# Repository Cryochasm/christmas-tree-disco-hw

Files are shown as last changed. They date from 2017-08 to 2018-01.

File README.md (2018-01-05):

# christmas-tree-disco-hw
KiCAD project for a Christmas Tree decoration.

Uses Texas Instruments LaunchPad **EK-TM4C123GXL** to control a 
shift register and RGB LEDs. Compatable with the 
430BOOST-C55AUDIO1 booster pack for the possibilty of timing 
the lights to music.

## Dependancies
* KiCAD nightly build
* KiBOM

## Folder Structure:  
- ***/PCB/***  
   Main Project: Christmas_Tree_Disco.pro  
   Top Level Schematic: Christmas_Tree_Disco.sch  
   Schematic Library: local.lib  

- ***/PCB/Fabrication***  
   PDFs of the schematics and PCB component layout  

- ***/PCB/Gerbers***  
   Generated gerber files  

- ***/PCB/local.pretty***  
   KiCad footprints used in this project  

- ***/PCB/local.pretty/packages3d***  
   3D models for the footprints

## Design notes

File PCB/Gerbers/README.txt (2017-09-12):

All files are in inches 
    
Format is 4.6mm

Solder-mask is Green 

Silkscreen is White

Surface finish is HASL
    
Copper weight is 1oz
    
PCB material is FR-4

PCB thickness is 1.6 mm

Layer Stackup is specified in the Fab Assembly file.

This section describes the function and purpose of the files.

    Christmas_Tree_Disco-B.Cu.gbr             Bottom copper layer
    Christmas_Tree_Disco-B.Fab.gbr            Bottom assembly layer
    Christmas_Tree_Disco-B.Mask.gbr           Bottom solder-mask layer
    Christmas_Tree_Disco-B.Paste.gbr          Bottom solder paste layer
    Christmas_Tree_Disco-B.SilkS.gbr          Bottom silkscreen layer
    Christmas_Tree_Disco-Edge.Cuts.gbr        Board outline
    Christmas_Tree_Disco-F.Cu.gbr             Top copper layer
    Christmas_Tree_Disco-F.Fab.gbr            Top assembly layer
    Christmas_Tree_Disco-F.Mask.gbr           Top solder-mask layer
    Christmas_Tree_Disco-F.Paste.gbr          Front solder paste layer
    Christmas_Tree_Disco-F.SilkS.gbr          Top silkscreen layer
    Christmas_Tree_Disco-PTH.drl              Plated through hole drill file
    Christmas_Tree_Disco.d356                 IPC-D-356 Netlist File
    Christmas_Tree_Disco-all-pos.csv          Pick and Place locations file

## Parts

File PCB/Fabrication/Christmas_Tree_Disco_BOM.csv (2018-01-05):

Have | Needed | Reference | Quantity | Value | Footprint | Datasheet | MPN | Description | Included in BOM
 | 35 | C0 C1 C10 C11 C12 C13 C14 C15 C2 C3 C4 C5 C6 C7 C9 | 15 | 0.1u | local:SMD-0805 | http://www.samsungsem.com/kr/support/library/product-catalog/mlcc.jsp | CL21B104KACWPNC | 0.1µF ±10% 25V Ceramic Capacitor X7R 0805 (2012 Metric) | Yes
1 | 3 | C16 C17 C8 | 3 | 10u | local:SMD-POL-1206 | http://datasheets.avx.com/F93.pdf | F931A106KAA | CAP TANT 10UF 10V 10% 1206 | Yes
12 | 25 | D0 D1 D10 D11 D12 D13 D14 D15 D2 D3 D4 D5 D6 D7 D9 | 15 | RGB LED | local:T-1_5mm | https://media.digikey.com/pdf/Data%20Sheets/Kingbright%20PDFs/WP154A4SEJ3VBDZGW-CA_Ver.1A_Jul-24-13.pdf | WP154A4SEJ3VBDZGW/CA | Red, Green, Blue (RGB) 625nm Red, 525nm Green, 470nm Blue LED Indication - Discrete 2.2V Red, 3.3V Green, 3.3V Blue Radial | Yes
 | N/A | D8 | 1 | SMBJ22D-M3/H | local:DO-214AA | http://www.vishay.com/docs/87606/87606.pdf | SMBJ22D-M3/H | TVS DIODE 22VWM 35.1VC DO214AA | Yes
 | N/A | F1 | 1 | 24V 3A | local:SMD-2920 | http://www.bourns.com/docs/Product-Datasheets/mflsmf.pdf | MF-LSMF300/24X-2 | Polymeric PTC Resettable Fuse 24V Ih Surface Mount 2920 (7351 Metric), Concave | Yes
 | 5 | H2 H4 | 2 | 2x10 HEADER | local:2x10_header_3d | http://www.molex.com/pdm_docs/sd/015912200_sd.pdf | 15912200 | 20 Positions Header, Breakaway Connector 0.100" (2.54mm) Surface Mount Tin | Yes
 | N/A | J1 | 1 | PJ-006B-SMT-TR | local:PJ-006B-SMT | http://www.cui.com/product/resource/pj-006b-smt.pdf | PJ-006B-SMT-TR | Power Barrel Connector Jack 2.50mm ID (0.098"), 5.50mm OD (0.217") Surface Mount | Yes
 | 3 | U2 | 1 | TLC5955DCA | local:HTSSOP-56_14x6.1 | http://www.ti.com/lit/ds/symlink/tlc5955.pdf | TLC5955DCAR | LED Driver IC 48 Output Linear Analog Dimming 30mA 56-HTSSOP | Yes
 | N/A | U3 | 1 | LM1085-5.0 | local:TO-263 | http://www.ti.com/lit/ds/symlink/lm1085.pdf | LM1085ISX-5.0/NOPB | Linear Voltage Regulator IC Positive Fixed Output 5V 3A DDPAK/TO-263-3 | Yes
 | N/A | H1 | 1 | LPRocket | local:LPRocket | - | - | - | No
 | N/A | H3 | 1 | Snow Silk Screen | local:snow | - | - | - | No
 | N/A | H5 | 1 | Power Supply 12V 24W | local:Do_Not_Populate | http://www.cui.com/product/resource/digikeypdf/swi24-n.pdf | SWI24-12-N-P6 | 12V 24W AC/DC External Wall Mount Adapter Fixed Blade Input | No
 | N/A | H6 | 1 | Power Info | local:Polarity | - | - | - | No
 | N/A | H7 | 1 | SPFMDBC | local:Open_Source_HW_Logo | - | - | - | No
 | 2 | U1 | 1 | DEV_KIT_EK-TM4C123GXL | local:DEV_KIT_EK-TM4C123GXL | http://www.ti.com/lit/ds/spms376e/spms376e.pdf | EK-TM4C123GXL | Development Boards & Kits - ARM TIVA LaunchPAD | No
 | 2 |  |  |  |  |  | 430BOOST-C55AUDIO1
 | N/A | V1.0 | 1 | www.github.com/Cryochasm | local:Cryochasm | - | - | - | No

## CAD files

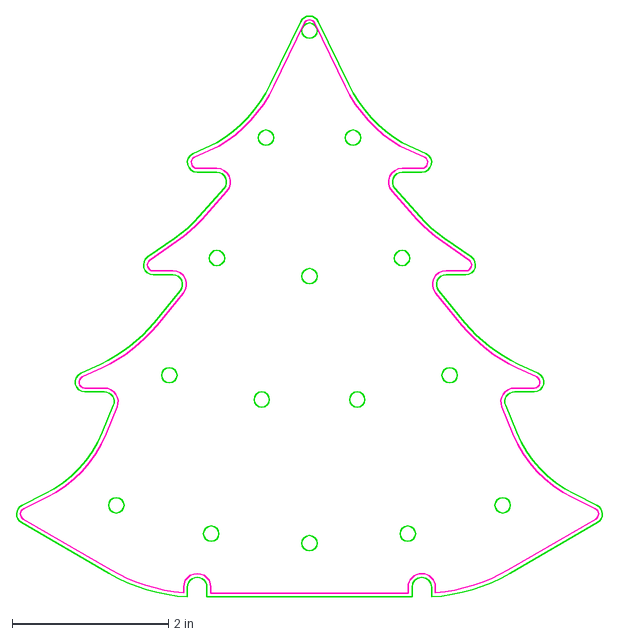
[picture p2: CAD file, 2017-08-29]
PCB.dxf
7.50 x 7.44 in

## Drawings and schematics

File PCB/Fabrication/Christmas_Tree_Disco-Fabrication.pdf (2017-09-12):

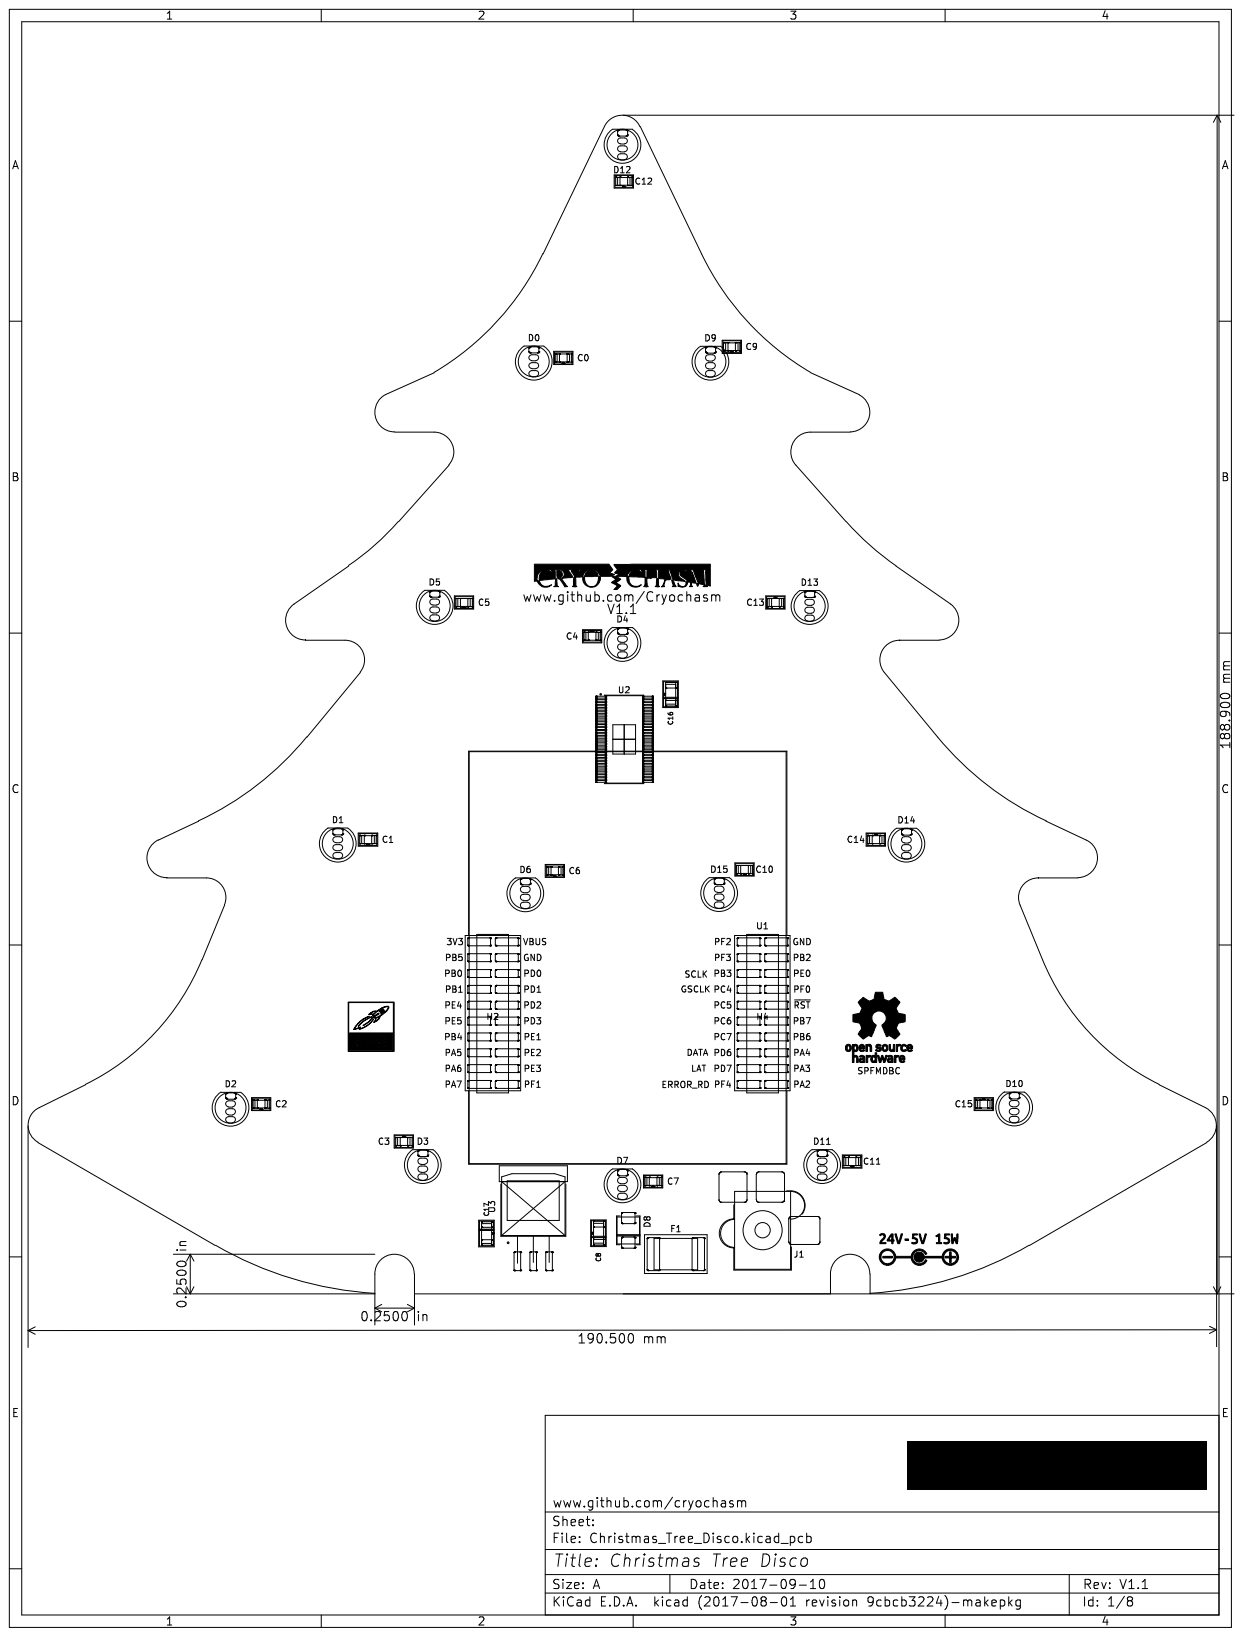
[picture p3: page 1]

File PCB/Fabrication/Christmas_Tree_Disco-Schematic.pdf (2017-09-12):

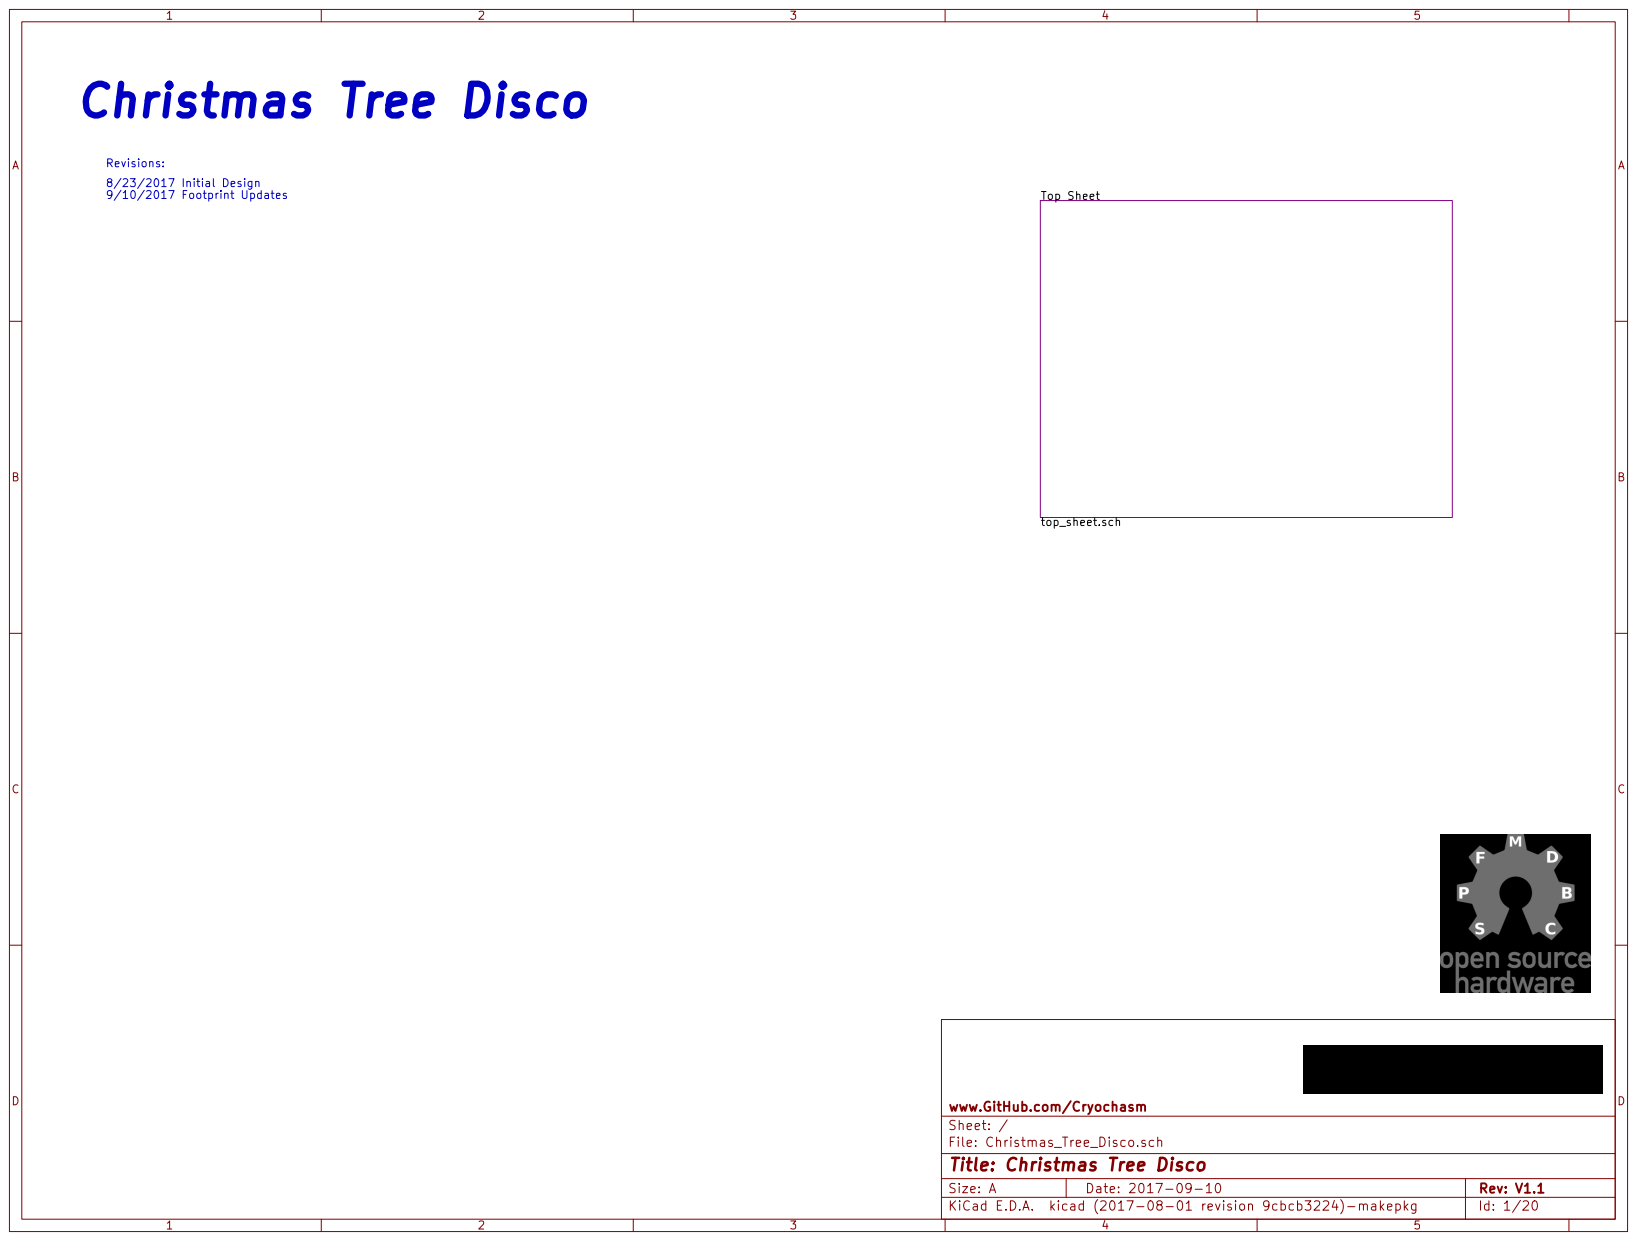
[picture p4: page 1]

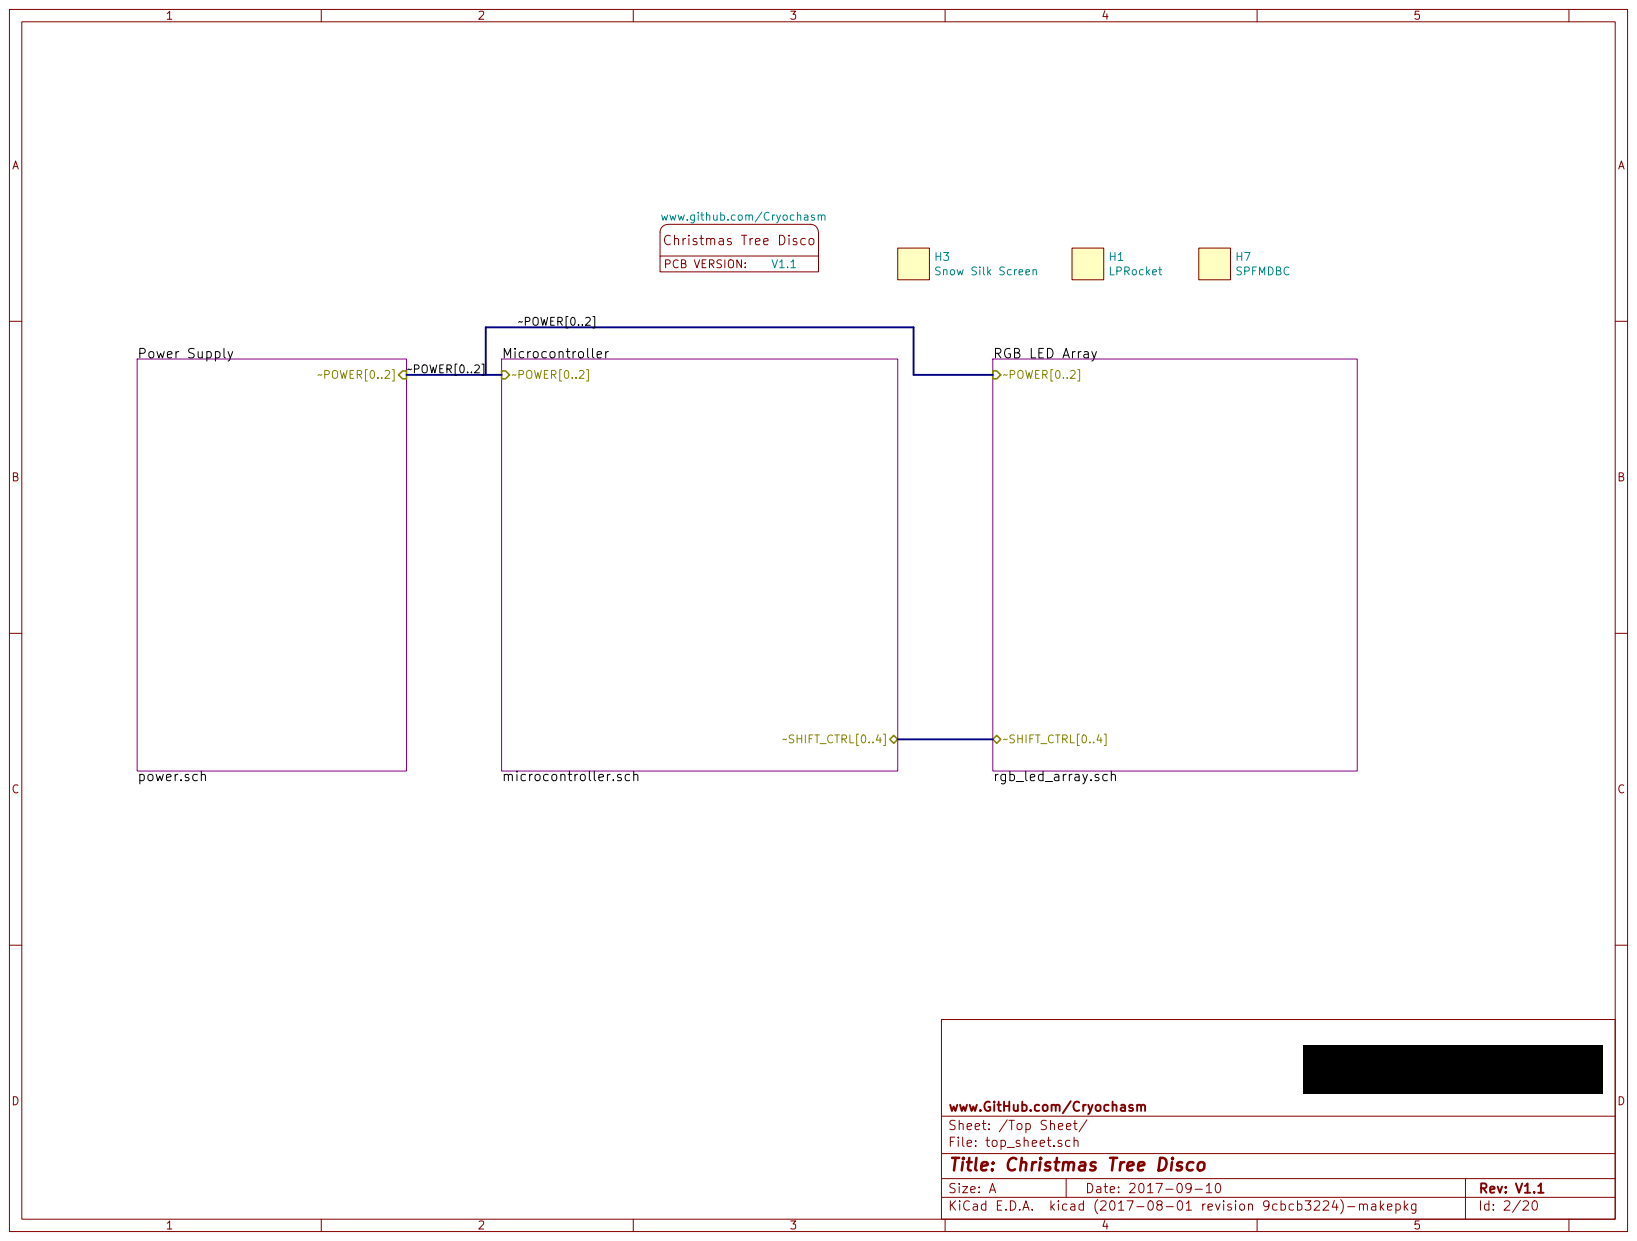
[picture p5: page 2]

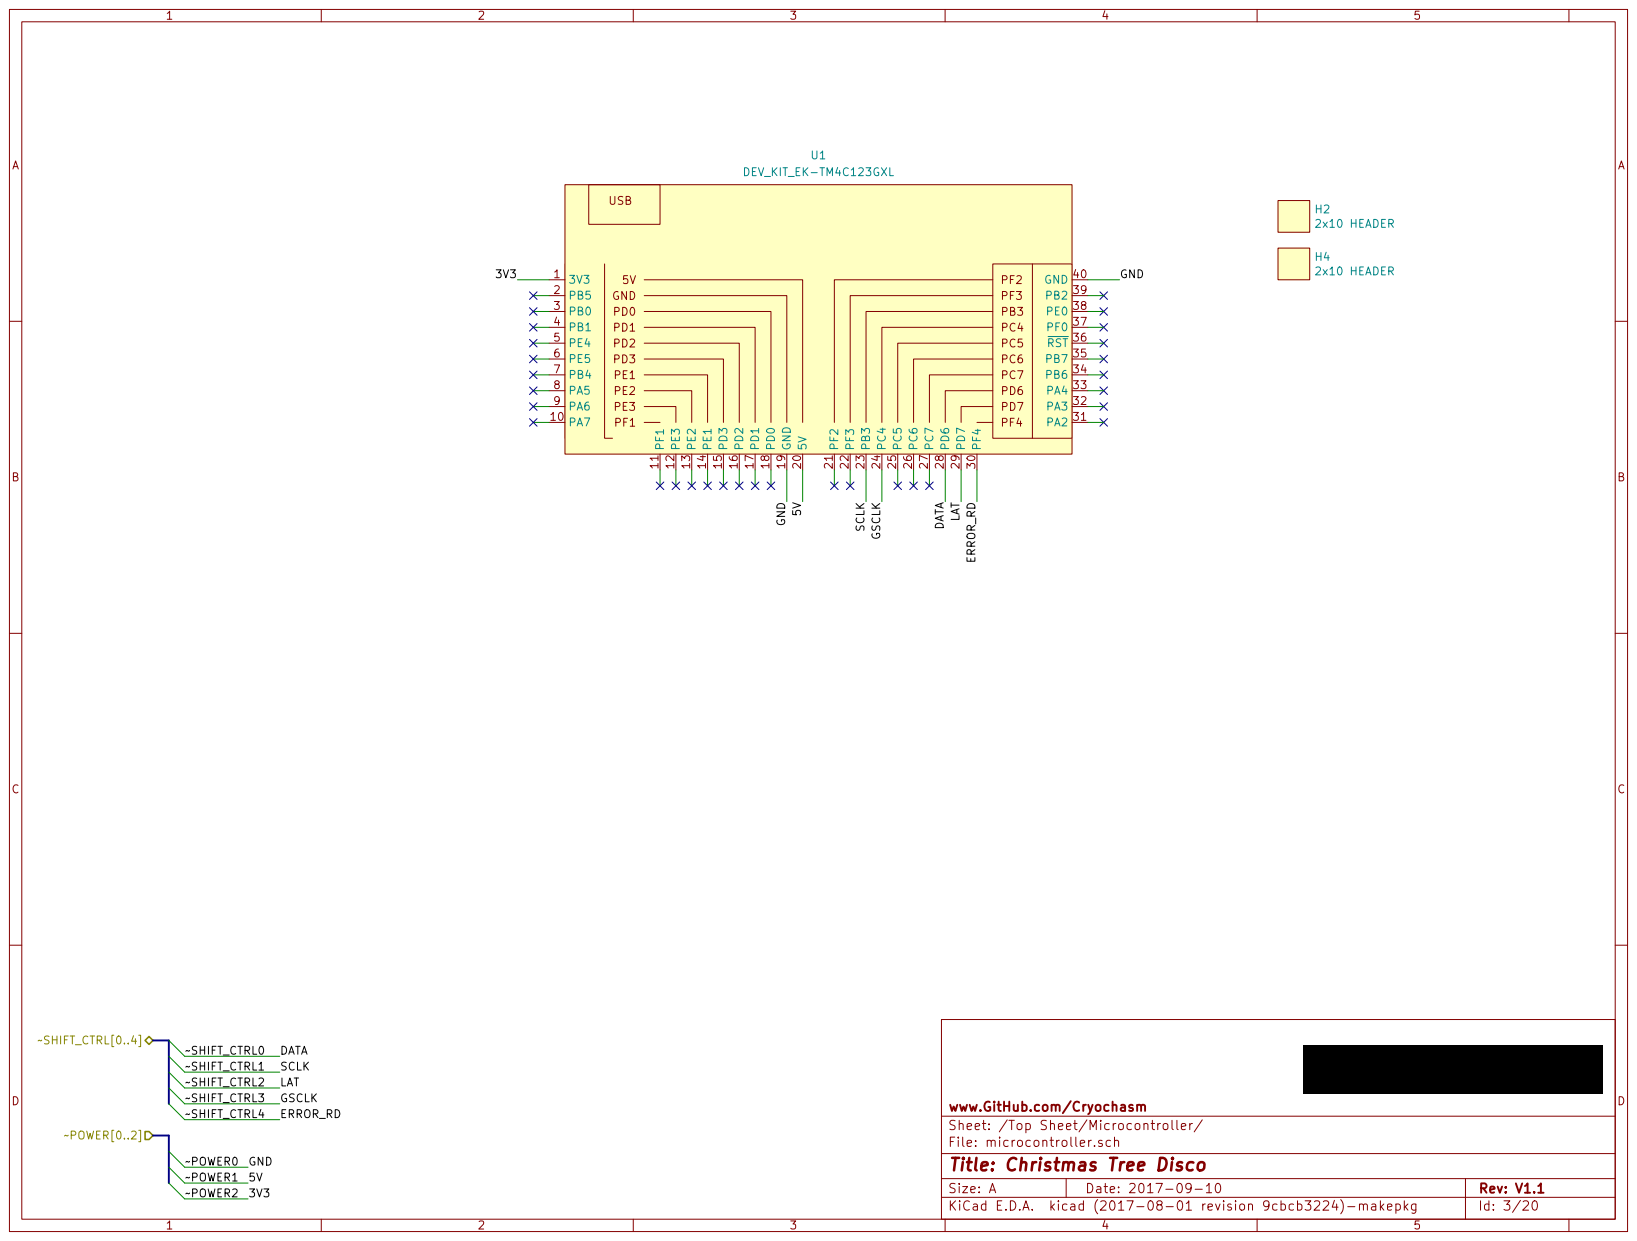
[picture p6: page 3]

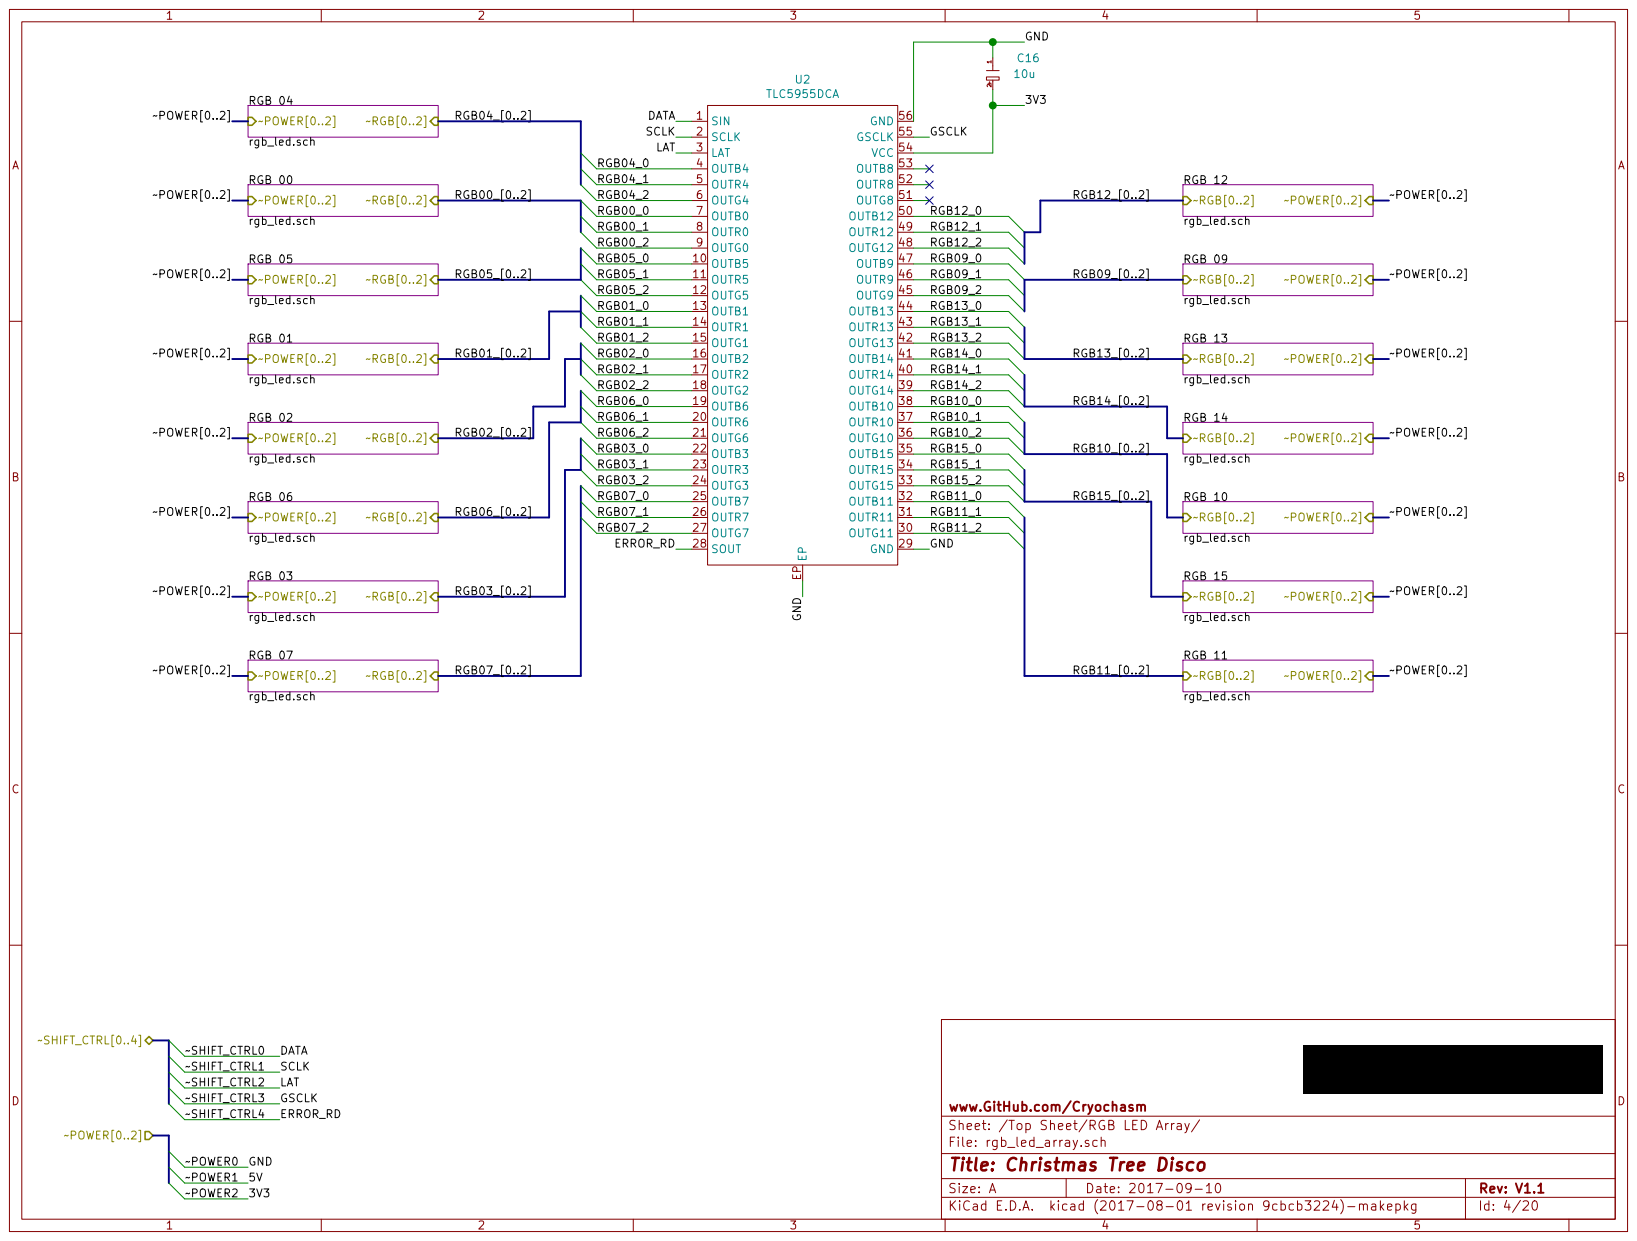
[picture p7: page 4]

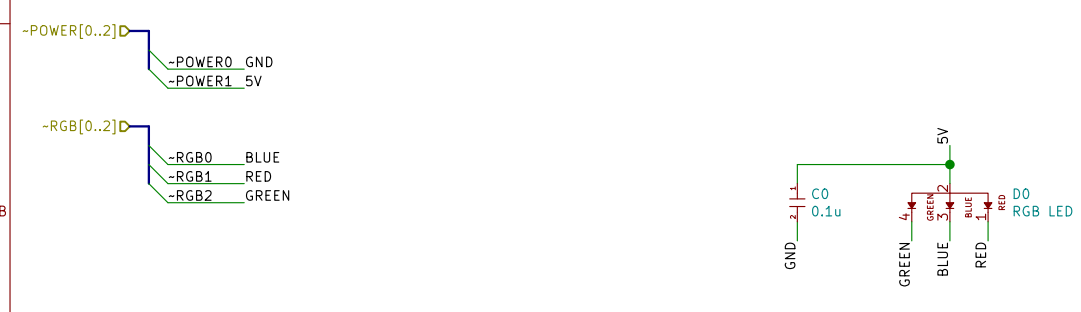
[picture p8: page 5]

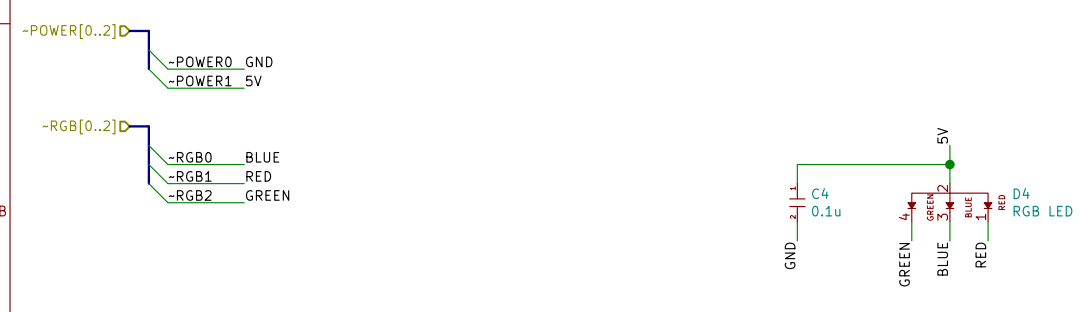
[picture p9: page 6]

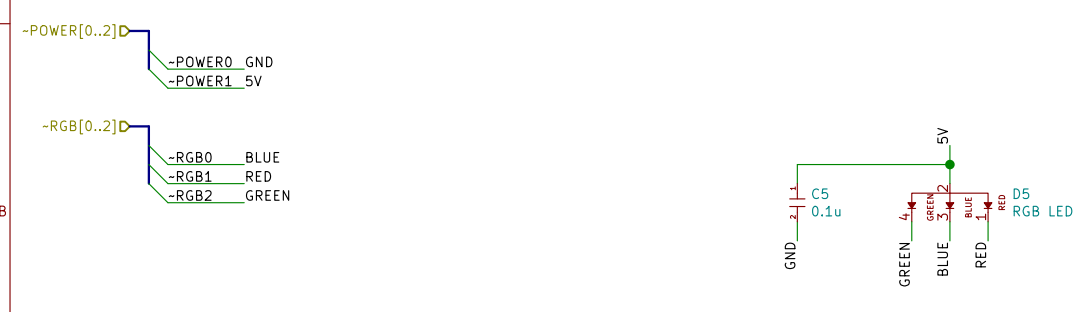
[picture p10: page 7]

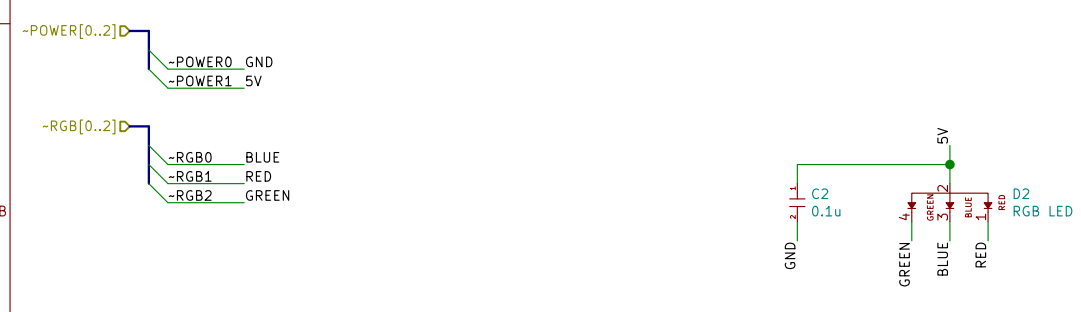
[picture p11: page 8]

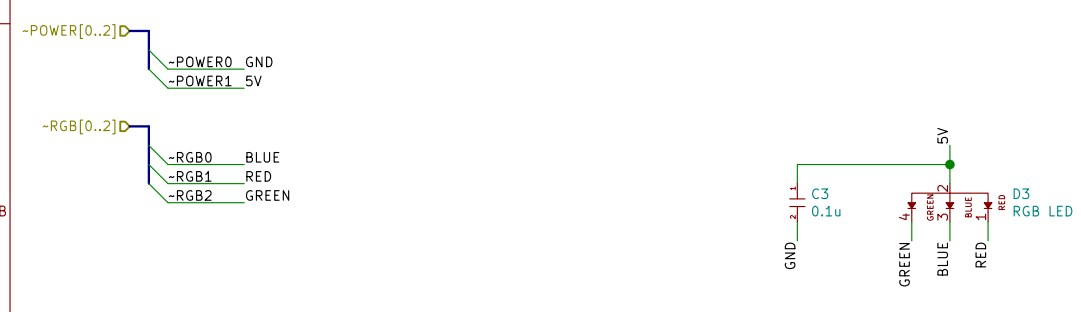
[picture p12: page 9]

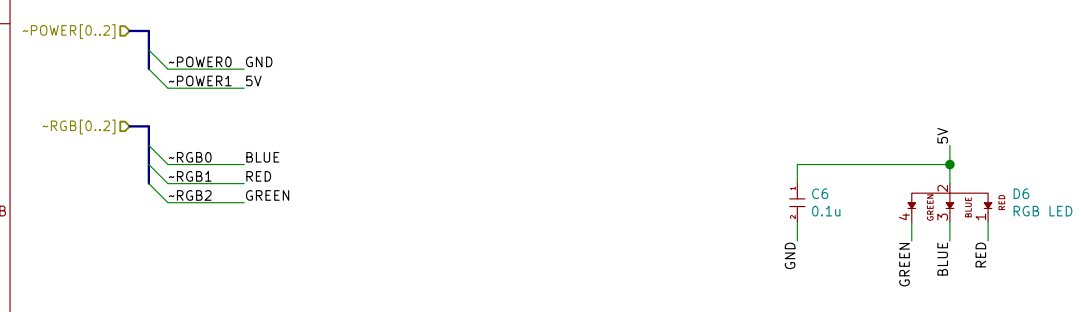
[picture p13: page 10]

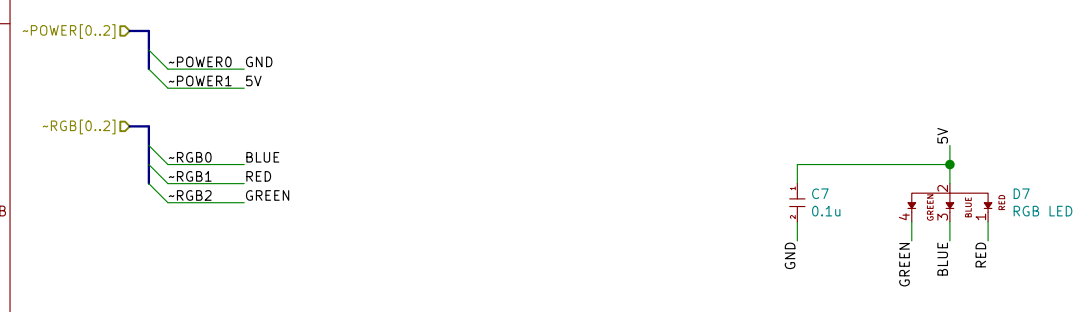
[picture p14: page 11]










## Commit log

2017-08-29 Picked LED and Shift Register
    [Christmas_Tree_Disco.kicad_pcb, Christmas_Tree_Disco.sch, microcontroller.sch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]
2017-08-29 PCB Edge.Cuts Defined
    [Christmas_Tree_Disco.kicad_pcb, Christmas_Tree_Disco.sch, PCB.dxf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]
2017-08-29 Removed extra LED
    [Christmas_Tree_Disco.kicad_pcb, Christmas_Tree_Disco.sch, microcontroller.sch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]
2017-08-29 Added Logic Level Conversion
    [Christmas_Tree_Disco.sch, microcontroller.sch, power.sch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]
2017-08-29 Preliminary PCB layout
    [Christmas_Tree_Disco.kicad_pcb, Christmas_Tree_Disco.sch, microcontroller.sch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]
2017-08-29 PCB Layout
    TODO: Change pinouts on dev kit to be compatable with Capacitive Touch
    Audio booster pack.
    [Christmas_Tree_Disco.kicad_pcb, microcontroller.sch, power.sch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]
2017-08-29 V1.0 Ready for Review
    Added compatability with the 430BOOST-C55AUDIO1 booster pack.
    [Christmas_Tree_Disco-B.Cu.gbl, Christmas_Tree_Disco-B.Fab.gbr, Christmas_Tree_Disco-B.Mask.gbs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]
2017-08-29 Gerber Updates
    [Christmas_Tree_Disco-B.Cu.gbl, Christmas_Tree_Disco-B.Fab.gbr, Christmas_Tree_Disco-B.Mask.gbs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]
2017-08-29 Added Open Hardware Logo
    [Christmas_Tree_Disco-B.Cu.gbl, Christmas_Tree_Disco-B.Fab.gbr, Christmas_Tree_Disco-B.Mask.gbs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]
2017-08-29 Removed Level Shifter, Cleaned up gerbers
    [Christmas_Tree_Disco-B.Cu.gbl, Christmas_Tree_Disco-B.Cu.gbr, Christmas_Tree_Disco-B.Fab.gbr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]
2017-09-12 Footprint Modifications
    [Christmas_Tree_Disco-B.Cu.gbr, Christmas_Tree_Disco-B.Fab.gbr, Christmas_Tree_Disco-B.Mask.gbr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]
2018-01-05 Schematic V2
    REQUIRES CHANGE TO SOFTWARE: Changed pin of LAT from D7 to D0 to avoid
    using the non-maskable interrupt pin.
    Added a SMD LED D8 to provide and enviornmental lighting effect.
    Removed power supply circuit; USB power from the dev board is sufficent
    for
    LED brightness. Must be plugged into USB 3.0 or a 2A rated supply.
    Updated symbol library to use KiBOM and to Lib Version 4.
    TODO: Update PCB
    [Christmas_Tree_Disco.kicad_pcb, Christmas_Tree_Disco.sch, Christmas_Tree_Disco_BOM.csv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]
